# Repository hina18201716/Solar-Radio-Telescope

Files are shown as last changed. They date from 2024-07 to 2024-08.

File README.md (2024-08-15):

# Solar Radio Telescope Upgrade

The solar radio telescope is located outside the visitor center at the Very Large Array site for educational purpose for visitors. The entire system of this telescope was re-designed, detecting RF energy and displaying DC voltage on Voltmeter. Construction and installation of the electrical system were done in August 2023 by the supporting team, who confirmed that the system was sufficiently functional. However, more improvement on the dynamic range on the voltmeter and additional indications were needed to attract a wider range of visitors in regards to age and background knowledge. 

The more detailed information can be found on report. https://www.overleaf.com/read/fyrtmdrdjbmg#2ac999

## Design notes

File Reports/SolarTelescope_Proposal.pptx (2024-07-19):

## Solar Telescope Proposal

June 2024
Hina Suzuki

## Project goals

- 1. Implementation of Solar finder
  - No solar finder is implemented to the solar telescope located outside of the visitor center.
  - When visitors align the solar telescope to the Sun, it require visitor to look up the Sun directly and point telescope to it.
  - Solar finder is needed to point the Sun more accurately without damaging users eyes.
- 2. Improvement on Indicator
  - 3V voltmeter was implemented as a indicator, however it does not clearly show difference on radio emission from the Sun and from ground/cold sky.
  - We aim to improve indicator (e.g. speaker) to make this more apparent and attractive.

## Timeline (Solar Finder)

1. Implementation of Solar finder

- Finalize design ( -12 June )
  - Choose the design of solar finder (design idea on next slide). The common and user-oriented design is demanded.
- 3D modeling dimensions ( - 19 June )
  - Design handy size finder with attachment based on measurement of existing telescope.
- 3D modeling & print prototype ( - 28 June )
  - Develop 3D modeling and materials may differ depending on finder design.
- Installation & Test ( - 3 July )
  - Install to the solar telescope and test finder.
- Demo ( 5 July )

## Solar Finder Design Ideas

#1 : Closed Tube

Semi- transparent

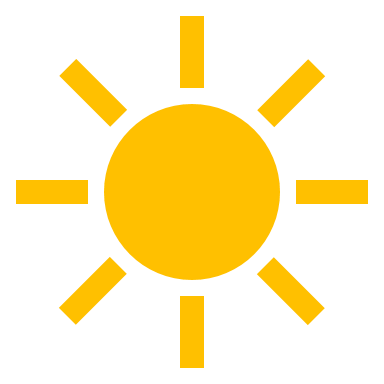
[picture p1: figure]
Sun

#2 : Open design

- Long lifetime
- Safe design for children
- Development complexity due to multiple materials
- Sun light ray may reach to the users eyes

- Easy to develop
- Possible injury due to design
- May easy to be broken
- User never need to look up the sky

For both design, we need to consider main material carefully so that solar finder will not melt in high temperature in summer season.
As the goal of solar finder was to prevent visitors from possible injury by aiming the telescope to the sun, we would user #2 Open Design.

## Timeline (Indicator)

2. Improvement on Indicator

- Explore why indicator is not sufficient to attract people ( - 12 June )
  - Test equipment behavior
  - Refer instruction for visitors
- Look back the telescope design ( - 21 June )
  - Re-write diagram of connection from receiver to voltmeter
  - Calculate estimated output on voltmeter
- Suggest method(s) for indicator improvement ( - 5 July )
  - Relatively small improvement if possible
  - Some rough ideas on next slides
- Design & develop new system ( - 2 August )
- Test & Demo ( - 14 August )
  - Install new system at the site and test its behavior

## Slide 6

- The higher value on voltmeter, the more LED light turns on.
- Colorful LEDs
- Require many LED for more precise indication
- Could be hard to maintain/ need to have regular maintenance
- No need to change instruction for visitor

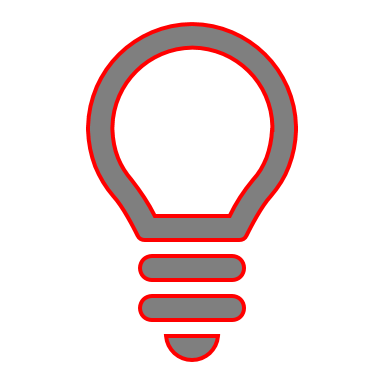
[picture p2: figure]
Lightbulb
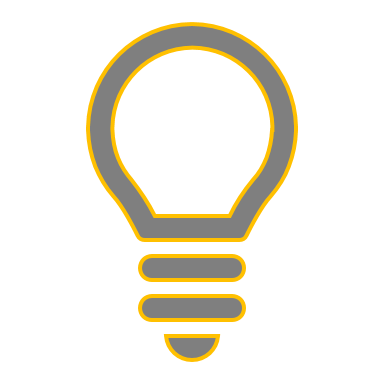
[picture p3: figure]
Lightbulb
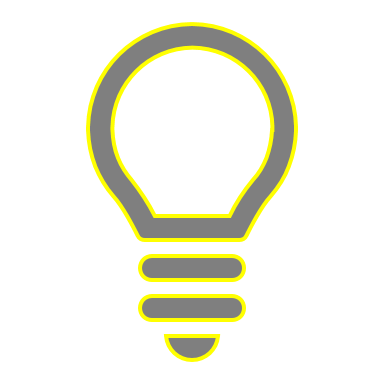
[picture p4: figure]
Lightbulb
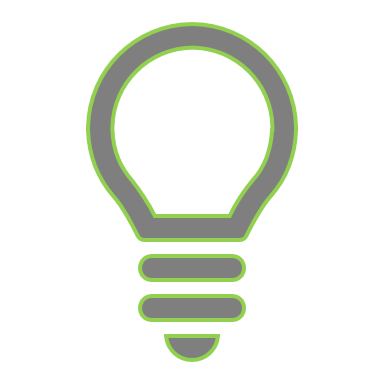
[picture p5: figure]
Lightbulb
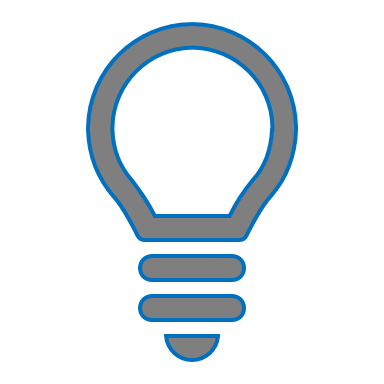
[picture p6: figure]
Lightbulb
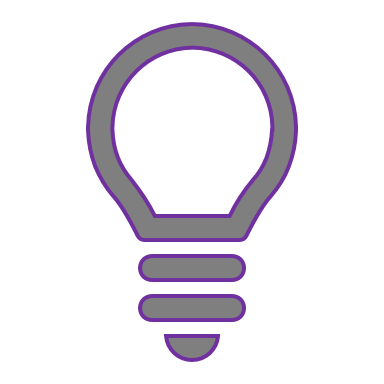
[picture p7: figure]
Lightbulb
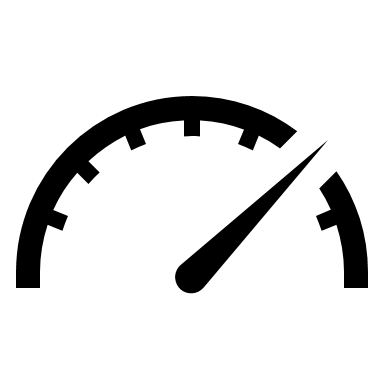
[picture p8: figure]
Gauge

Ground

Sun

Satellite

- Install 3 LEDs lighten up when Sun, Ground, Satellite is pointed
- No need to change instruction
- Need cover
- Values differ on each day (Atmospheric conditions, solar activities)

Need to have cover to make LED lights visible in the sun

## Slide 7

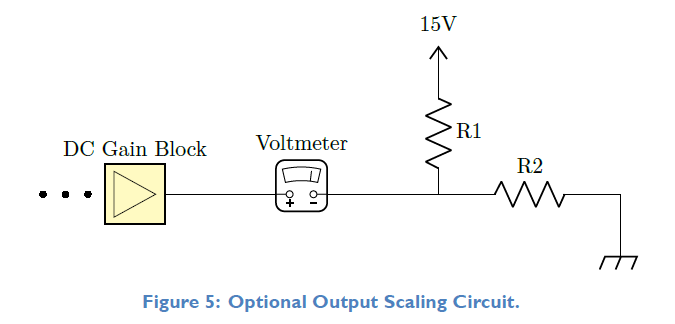
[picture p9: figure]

- Change offset value of voltmeter
- Cold sky ≈ 0 V

- Change Gain factor
- Use 0 – 5 V

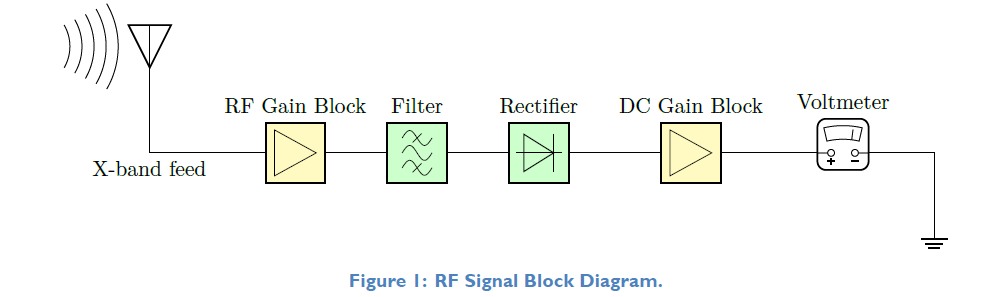
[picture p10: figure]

- It may problem when telescope catch the satellite signals
- Need to re-calculate gain factor, offset value depending on solar activity cycle (increase 2 more years and decrease after)

Credit : Redesign of the Visitor Center Solar Telescope, Nguyen. R

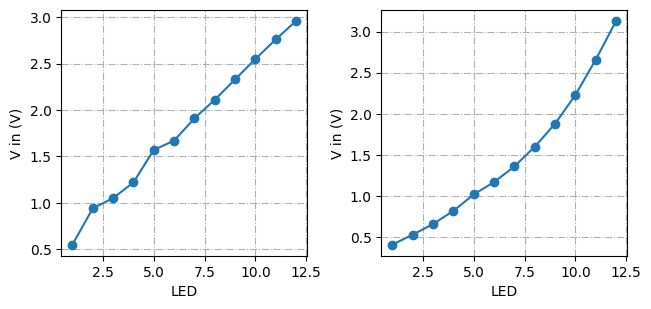
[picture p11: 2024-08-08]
Reports/output.png

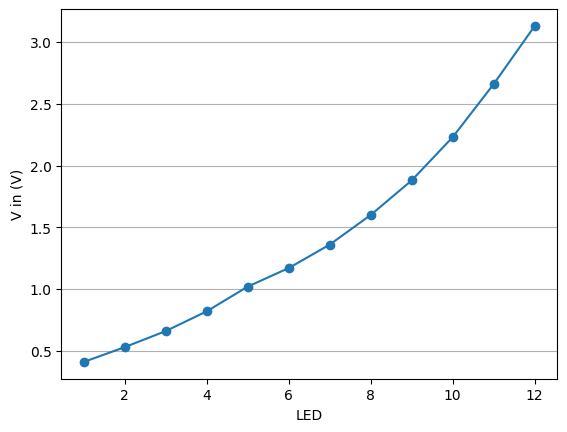
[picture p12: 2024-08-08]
Reports/nonlinear.png

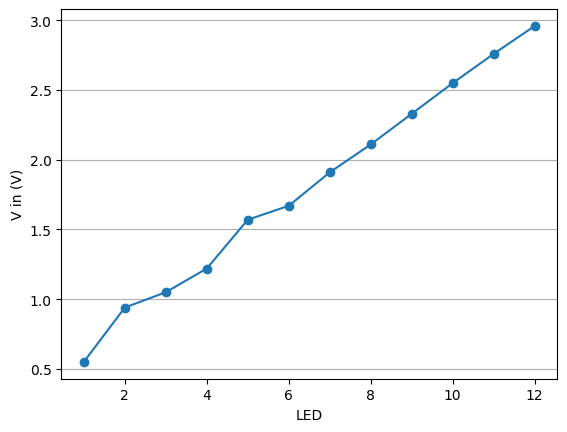
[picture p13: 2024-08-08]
Reports/linear.png

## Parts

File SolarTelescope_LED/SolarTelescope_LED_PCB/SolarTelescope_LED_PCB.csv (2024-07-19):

Id | Designator | Footprint | Quantity | Designation | Supplier and ref
1 | R4,R8,R2,R3,R22,R24,R16,R15,R9,R21,R18,R25,R19,R7,R17,R10,R5,R14,R12,R1,R6,R11,R20,R23 | R_0805_2012Metric_Pad1.20x1.40mm_HandSolder | 24 | 1k
2 | D6,D12,D1,D2,D5,D10,D7,D11,D3,D4,D9,D8 | LED_D5.0mm | 12 | LED
3 | J1 | TerminalBlock_Phoenix_MKDS-3-5-5.08_1x05_P5.08mm_Horizontal | 1 | Screw_Terminal_01x05
4 | R13 | R_0805_2012Metric_Pad1.20x1.40mm_HandSolder | 1 | R
5 | U1,U2,U3 | DIP-14_W7.62mm | 3 | LM324

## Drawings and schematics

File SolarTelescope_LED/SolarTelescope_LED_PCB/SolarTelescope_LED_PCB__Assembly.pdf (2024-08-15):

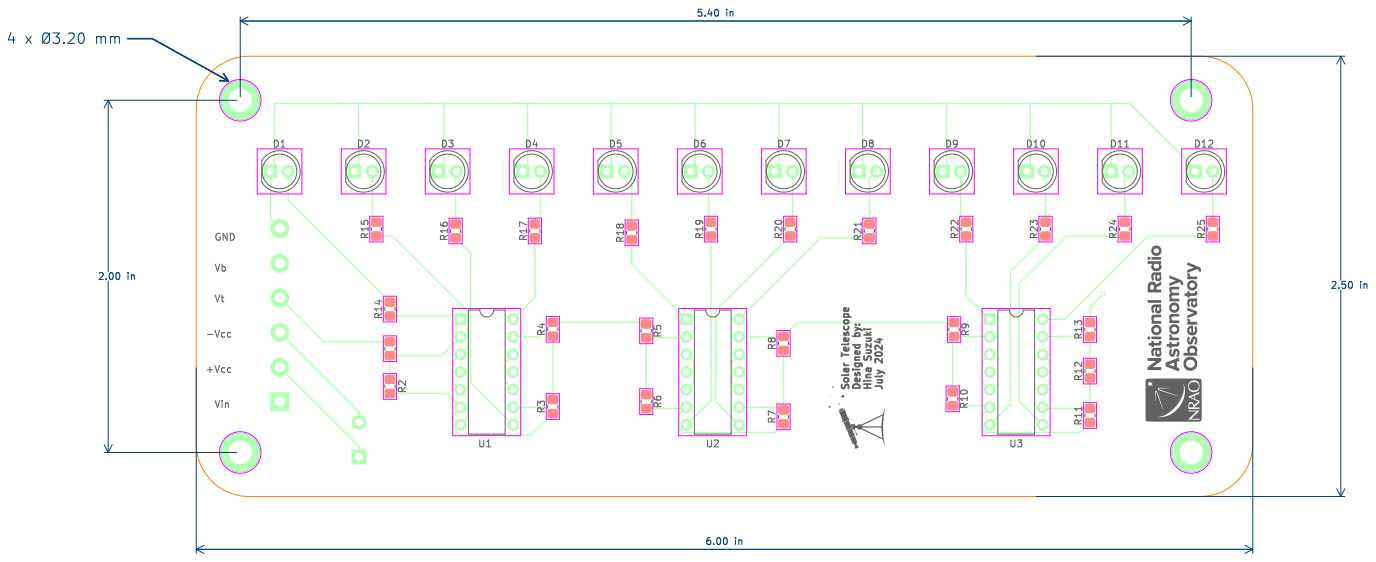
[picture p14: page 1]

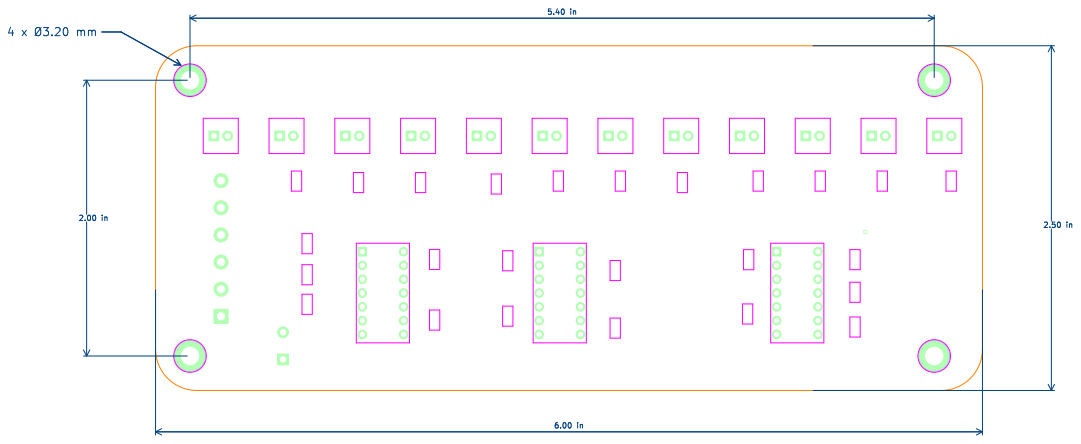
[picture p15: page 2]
D Date: 2024-08-13 KiCad; E.D.A. 8.0.3 Size: USLetter; Rev: 2.0; Id: 1/1 Title: Op amp, level comparator,; LED; File: SolarTelescope_LED_PCB.kicad_pcb Sheet: National; Radio Astronomy; Observatory,; Hina Suzuki

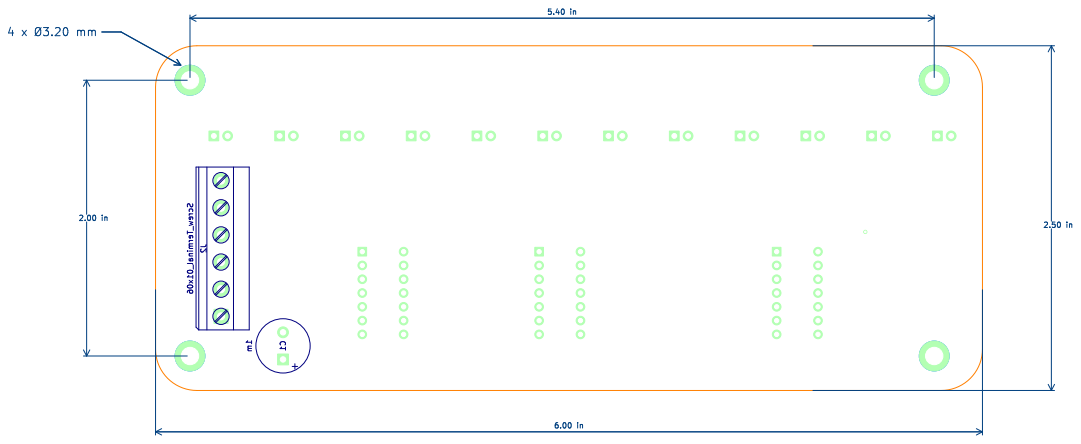
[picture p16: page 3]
D Date: 2024-08-13 KiCad; E.D.A. 8.0.3 Size: USLetter; Rev: 2.0; Id: 1/1 Title: Op amp, level comparator,; LED; File: SolarTelescope_LED_PCB.kicad_pcb Sheet: National; Radio Astronomy; Observatory,; Hina Suzuki ¹m; C1 Screw_Terminal_01x06

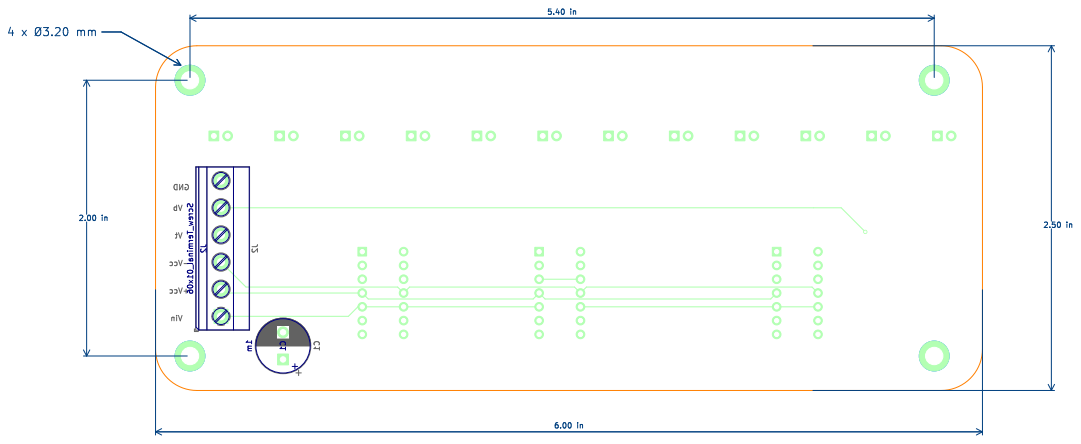
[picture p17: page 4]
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

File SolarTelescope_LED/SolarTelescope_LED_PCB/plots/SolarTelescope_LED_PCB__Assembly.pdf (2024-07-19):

D12 1 | 2 | 3 | 4 | 5

A

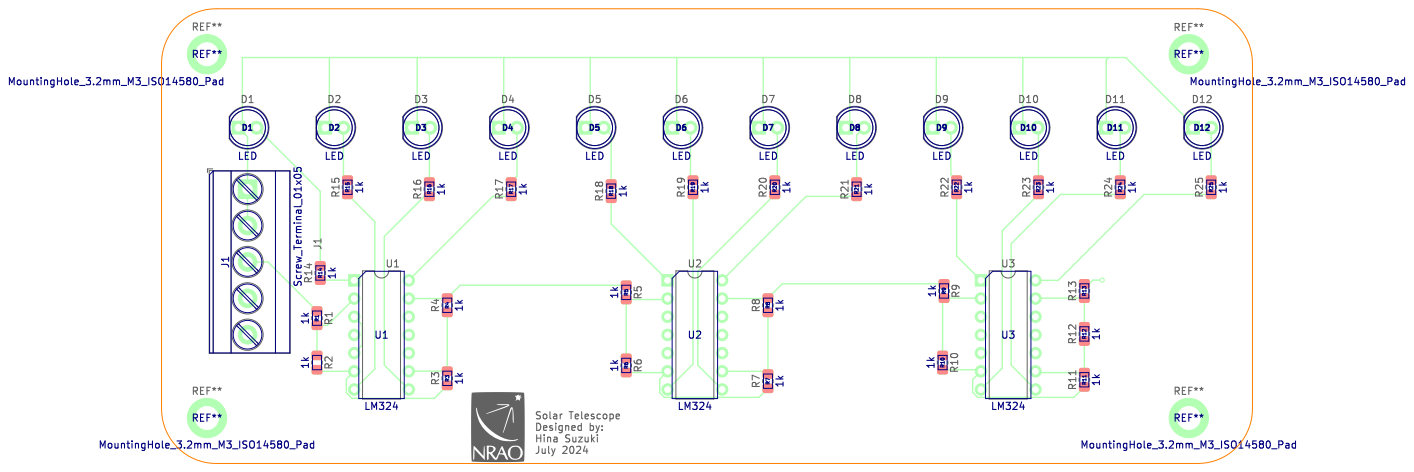
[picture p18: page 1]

1 | 2 | 3 | 4 | 5

A

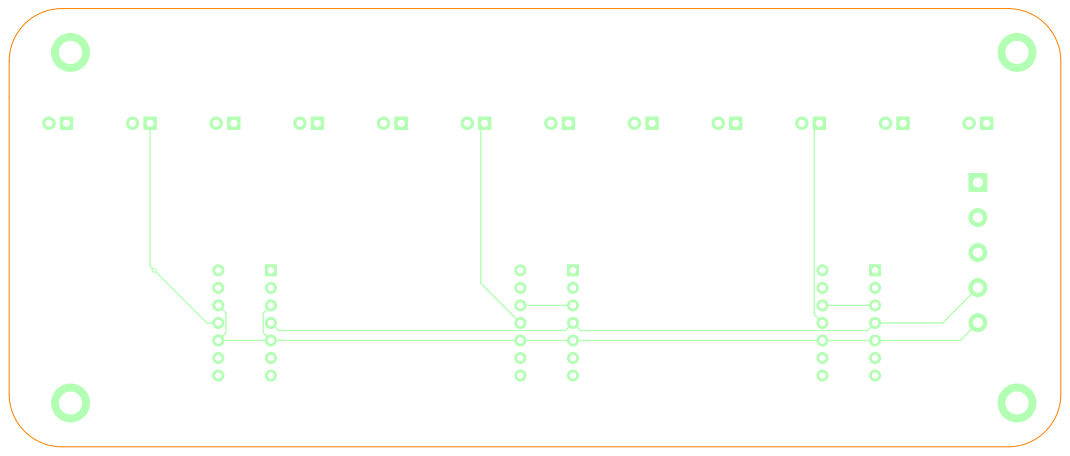
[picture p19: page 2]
D Date: 2024-07-08 KiCad; E.D.A. 8.0.3 Size: USLetter; Rev: 1.0; Id: 1/1 Title: Op amp, level comparator,; LED; File: SolarTelescope_LED_PCB.kicad_pcb Sheet: National; Radio Astronomy; Observatory

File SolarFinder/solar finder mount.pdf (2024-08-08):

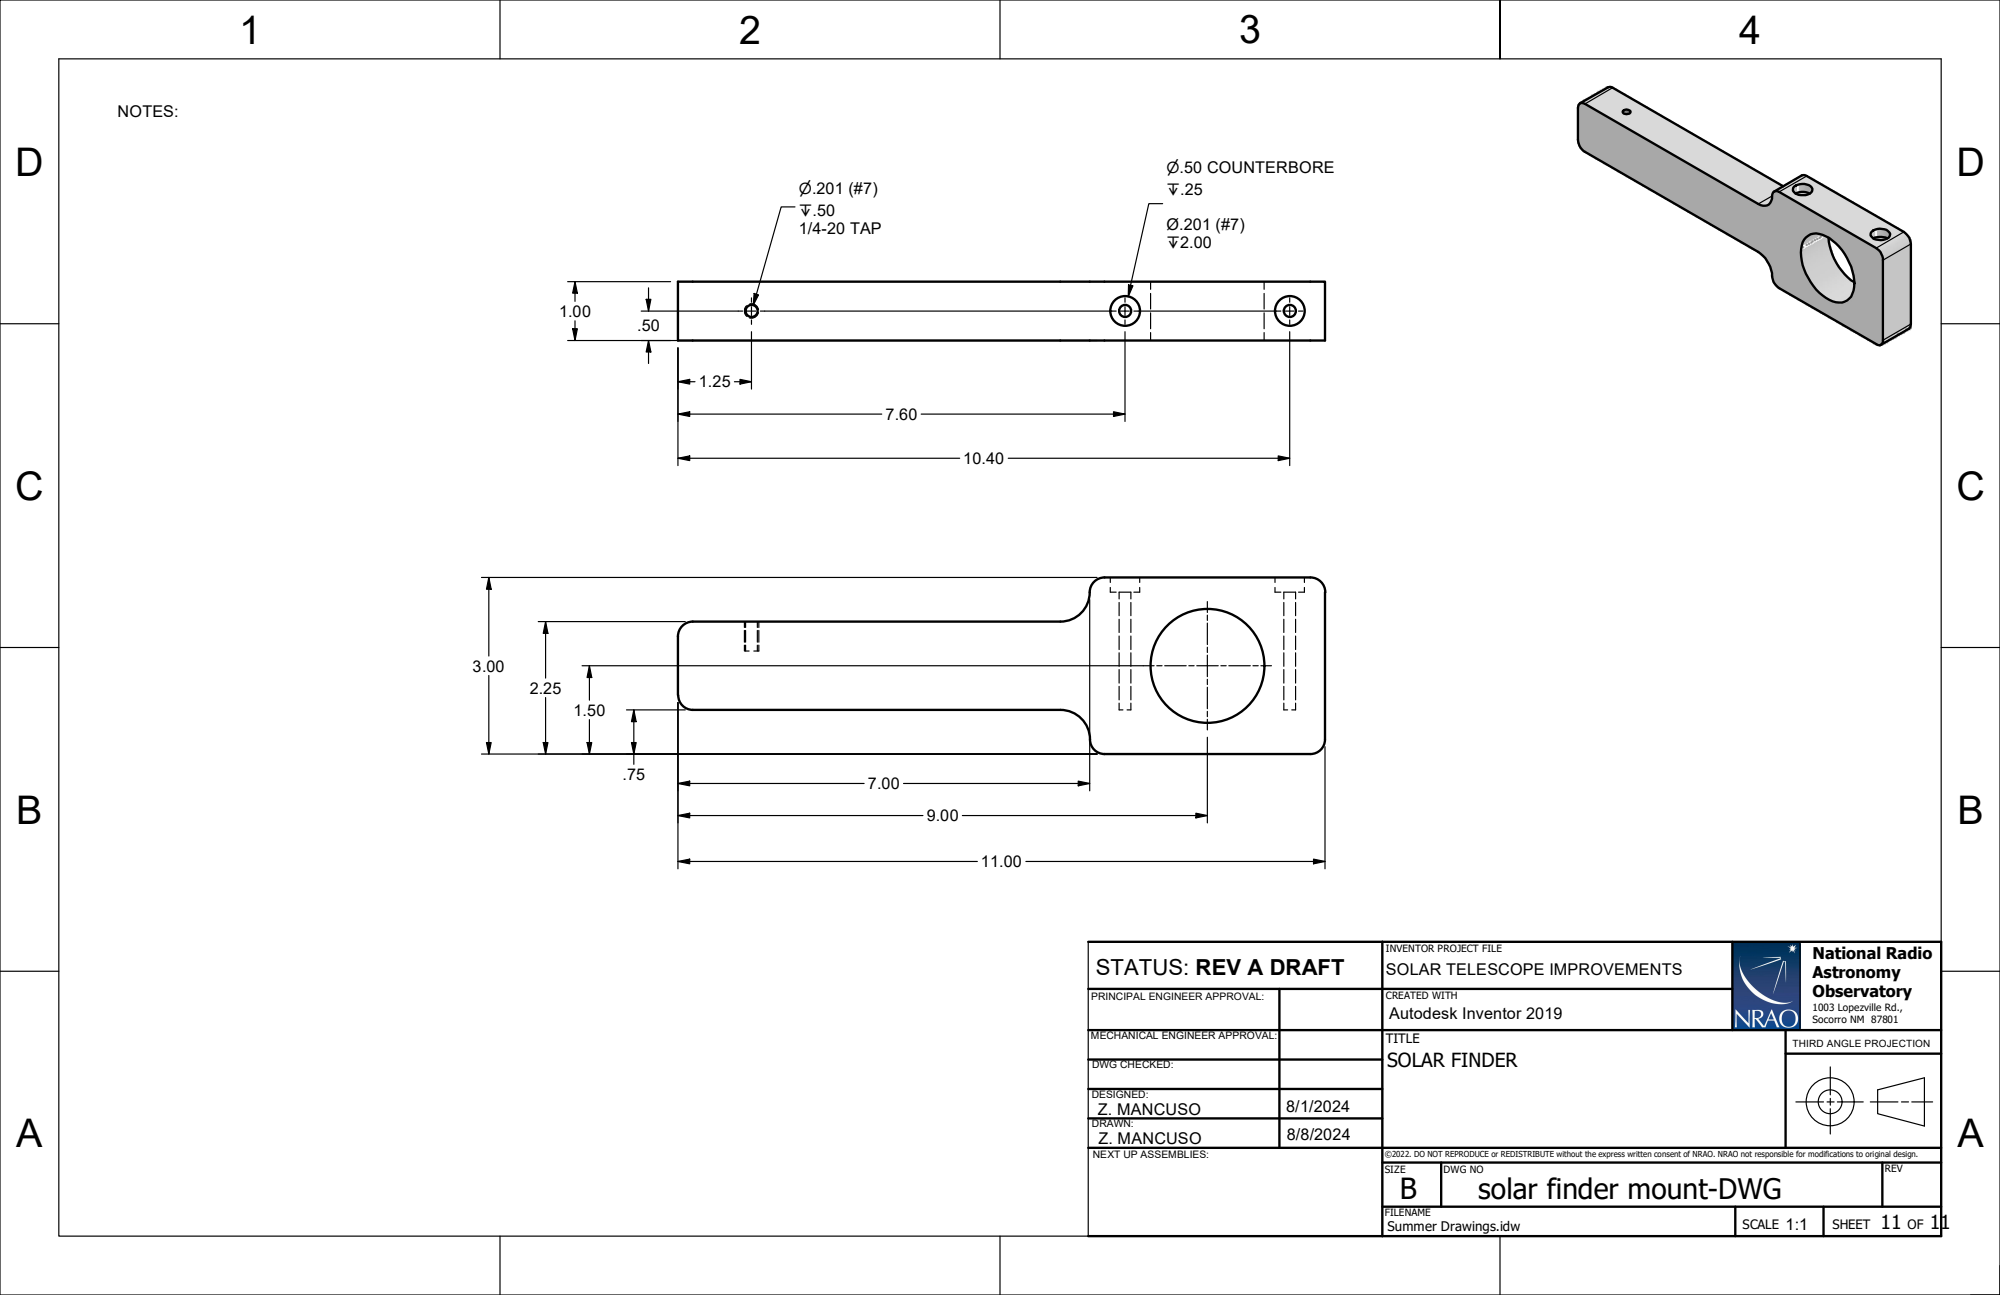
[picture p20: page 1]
SHEET 11 OF 11; 1/4-20 TAP

STATUS: REV A DRAFT | INVENTOR PROJECT FILE SOLAR TELESCOPE IMPROVEMENTS | | National Radio Astronomy Observatory 1003 Lopezville Rd., Socorro NM 87801

PRINCIPAL ENGINEER APPROVAL: | | CREATED WITH Autodesk Inventor 2019

MECHANICAL ENGINEER APPROVAL: | | TITLE SOLAR FINDER | THIRD ANGLE PROJECTION

DWG CHECKED:

DESIGNED: Z. MANCUSO | 8/1/2024

DRAWN: Z. MANCUSO | 8/8/2024

NEXT UP ASSEMBLIES: | ©2022. DO NOT REPRODUCE or REDISTRIBUTE without the express written consent of NRAO. NRAO not responsible for modifications to original design.

SIZE B | DWG NO solar finder mount-DWG | REV

FILENAME Summer Drawings.idw | SCALE 1:1

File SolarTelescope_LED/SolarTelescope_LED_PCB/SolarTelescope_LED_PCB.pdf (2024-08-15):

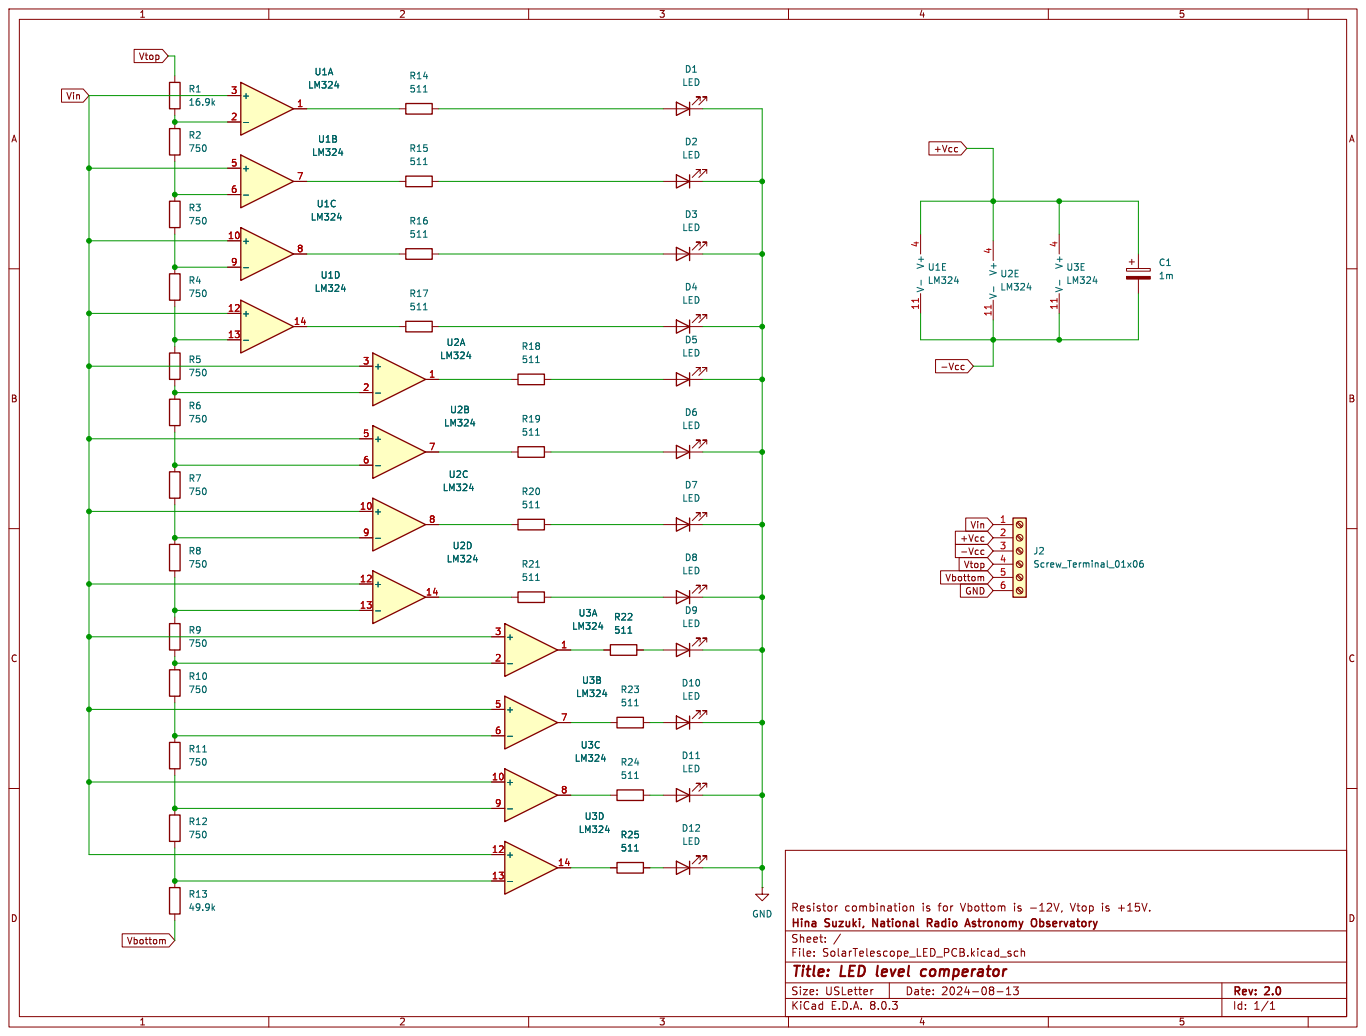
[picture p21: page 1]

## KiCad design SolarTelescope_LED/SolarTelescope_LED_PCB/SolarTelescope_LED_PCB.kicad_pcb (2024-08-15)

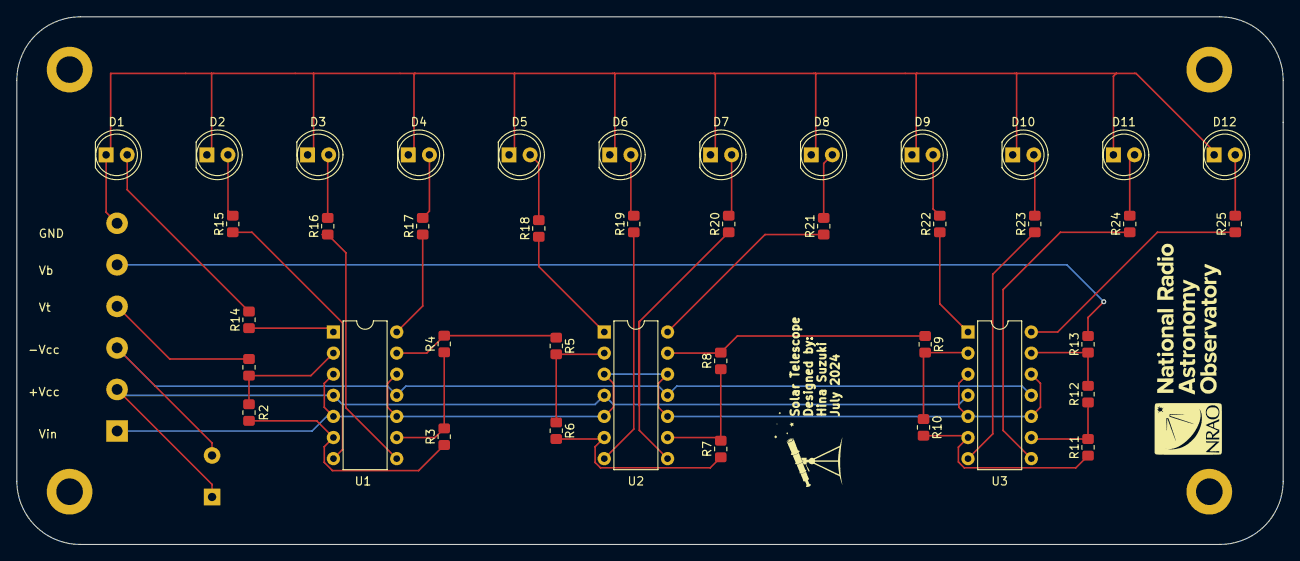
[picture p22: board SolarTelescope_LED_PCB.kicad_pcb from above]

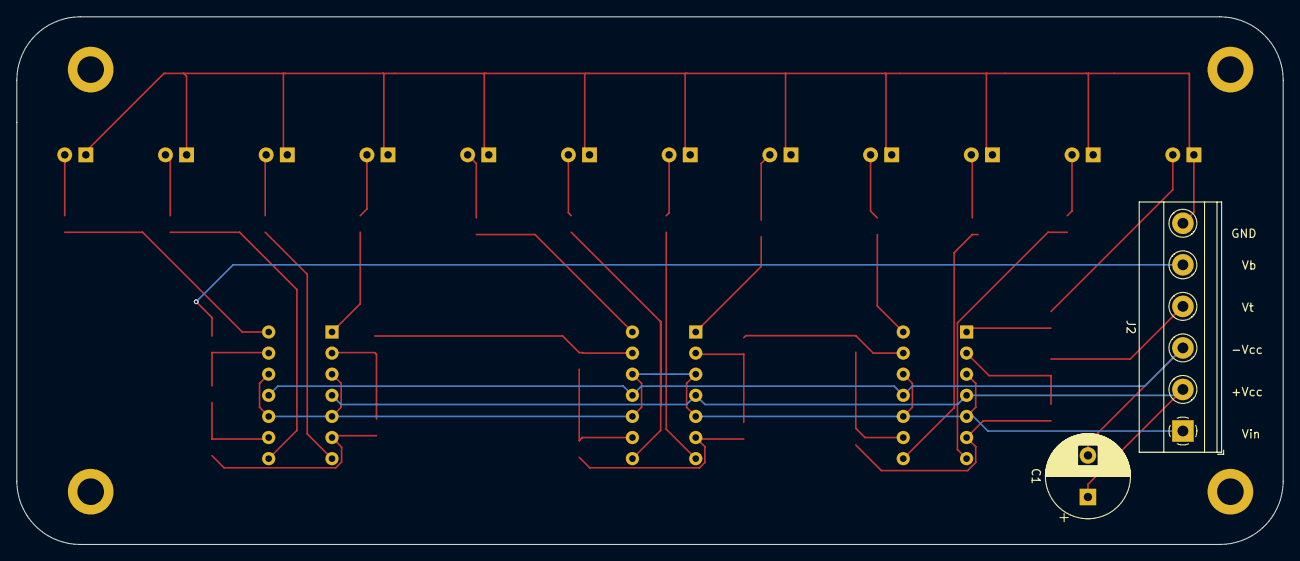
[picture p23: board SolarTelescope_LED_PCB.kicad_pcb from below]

Board: 2 copper layers, 152.4 x 63.5 mm, 42 parts (2 on the bottom side), 42 nets.

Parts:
C1: 1m; CP_Radial_D10.0mm_P5.00mm
D1, D2, D3, D4, D5, D6, D7, D8, D9, D10, D11, D12: LED; LED_D5.0mm
J2: Screw_Terminal_01x06; TerminalBlock_Phoenix_MKDS-1,5-6_1x06_P5.00mm_Horizontal
R1: 48k; R_0805_2012Metric_Pad1.20x1.40mm_HandSolder
R2, R3, R4, R5, R6, R7, R8, R9, R10, R11, R12, R13: 1k; R_0805_2012Metric_Pad1.20x1.40mm_HandSolder
R14, R15, R16, R17, R18, R19, R20, R21, R22, R23, R24, R25: 511; R_0805_2012Metric_Pad1.20x1.40mm_HandSolder
U1, U2, U3: LM324; DIP-14_W7.62mm

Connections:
+Vcc: C1.1, J2.2, U1.4 (V+), U2.4 (V+), U3.4 (V+)
-Vcc: C1.2, J2.3, U1.11 (V-), U2.11 (V-), U3.11 (V-)
GND: D1.1 (K), D2.1 (K), D3.1 (K), D4.1 (K), D5.1 (K), D6.1 (K), D7.1 (K), D8.1 (K), D9.1 (K), D10.1 (K), D11.1 (K), D12.1 (K), J2.6
unnamed: D1.2 (A), R14.2
unnamed: D2.2 (A), R15.2
unnamed: D3.2 (A), R16.2
unnamed: D4.2 (A), R17.2
unnamed: D5.2 (A), R18.2
unnamed: D6.2 (A), R19.2
unnamed: D7.2 (A), R20.2
unnamed: D8.2 (A), R21.2
unnamed: D9.2 (A), R22.2
unnamed: D10.2 (A), R23.2
unnamed: D11.2 (A), R24.2
unnamed: D12.2 (A), R25.2
unnamed: R14.1, U1.1
unnamed: R15.1, U1.7
unnamed: R16.1, U1.8
unnamed: R17.1, U1.14
unnamed: R18.1, U2.1
unnamed: R19.1, U2.7
unnamed: R20.1, U2.8
unnamed: R21.1, U2.14
unnamed: R22.1, U3.1
unnamed: R23.1, U3.7
unnamed: R24.1, U3.8
unnamed: R25.1, U3.14
unnamed: R1.2, R2.1, U1.2 (-)
unnamed: R2.2, R3.1, U1.6 (-)
unnamed: R3.2, R4.1, U1.9 (-)
unnamed: R4.2, R5.1, U1.13 (-)
unnamed: R5.2, R6.1, U2.2 (-)
unnamed: R6.2, R7.1, U2.6 (-)
unnamed: R7.2, R8.1, U2.9 (-)
unnamed: R8.2, R9.1, U2.13 (-)
unnamed: R9.2, R10.1, U3.2 (-)
unnamed: R10.2, R11.1, U3.6 (-)
unnamed: R11.2, R12.1, U3.9 (-)
unnamed: R12.2, R13.1, U3.13 (-)
Vbottom: J2.5, R13.2
Vin: J2.1, U1.3 (+), U1.5 (+), U1.10 (+), U1.12 (+), U2.3 (+), U2.5 (+), U2.10 (+), U2.12 (+), U3.3 (+), U3.5 (+), U3.10 (+), U3.12 (+)
Vtop: J2.4, R1.1

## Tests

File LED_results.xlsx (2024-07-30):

Linear LEDs
 | LED # | Turning on Voltage
 | 1 | 0.55
 | 2 | 0.94
 | 3 | 1.05
 | 4 | 1.22
 | 5 | 1.57
 | 6 | 1.67
 | 7 | 1.91
 | 8 | 2.11
 | 9 | 2.33
 | 10 | 2.55
 | 11 | 2.76
 | 12 | 2.96

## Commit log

2024-07-30 added solarfinder, results, and demo
    [LED_results.xlsx]
2024-08-07 latex circuitikz manual added
2024-08-08 LED array result added
2024-08-15 Version B.
    [SolarTelescope_LED_PCB-B_Cu.gbr, SolarTelescope_LED_PCB-B_Mask.gbr, SolarTelescope_LED_PCB-B_Paste.gbr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]
